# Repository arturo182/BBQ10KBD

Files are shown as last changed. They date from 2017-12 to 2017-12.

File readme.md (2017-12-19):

# Blackberry Q10 Keyboard

This document tries to summarize all the findings about the Blackberry Q10 keyboard, which seems interesting for DIY projects.
The keyboard has a nice feel to it, is just the right size for typing and is fairly cheap (around 3 USD on Aliexpress).  
It's available in black and white, there are versions with other letters like Arabic and Russian in addition to Latin. See [6] for details.  
It also has a 4 LED backlight and a built-in MEMS microphone which can come in handy.

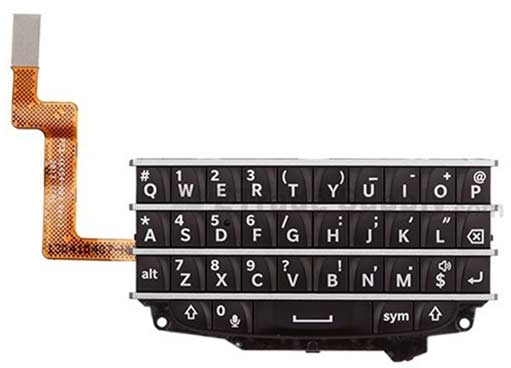
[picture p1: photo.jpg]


### Reversing on the pinout

Most of the work was done by others in [2] and [1], but after discovering the microphone, I was curious to see how it was connected and get the complete pinout of the keyboard. The flex PCB inside the keyboard is covered with a black film, but it is possible to remove the film by lifting a edge with a scalpel and slowly peeling it off, it might break mid-way but you can just lift the corner and continue.

A high resolution scan of the flex is available in this respository in `flex_scan.png`

Pinout:
```

    GND   1 | 28  GND
MIC_VDD   2 | 27  ROW7
    MIC   3 | 26  LEDA 1 & 2
   AGND   4 | 25  LEDK 1 & 4
    GND   5 | 24  LEDA 3 & 4
   ROW1   6 | 23  LEDK 2 & 3
   COL1   7 | 22  ROW6
   ROW2   8 | 21  ROW5
   COL2   9 | 20  ROW4
   COL3  10 | 19  COL5
    GND  11 | 18  ROW3
    GND  12 | 17  COL4
    GND  13 | 16  GND
    GND  14 | 15  GND
```

Since the numbering can be confusing (is it the plug or the receptacle?), see footprint below for clarification.

### KiCad resources

NOTE: These are not yet tested and while they are based on other people's working prototypes, I can't give a 100% guarantee these are correct, once I receive my board and verify everything, I will modify the document to reflect my findings.

Here is the final schematic symbol with the complete pinout, only one GND is visible, the rest is stacked under it and set to be invisible.

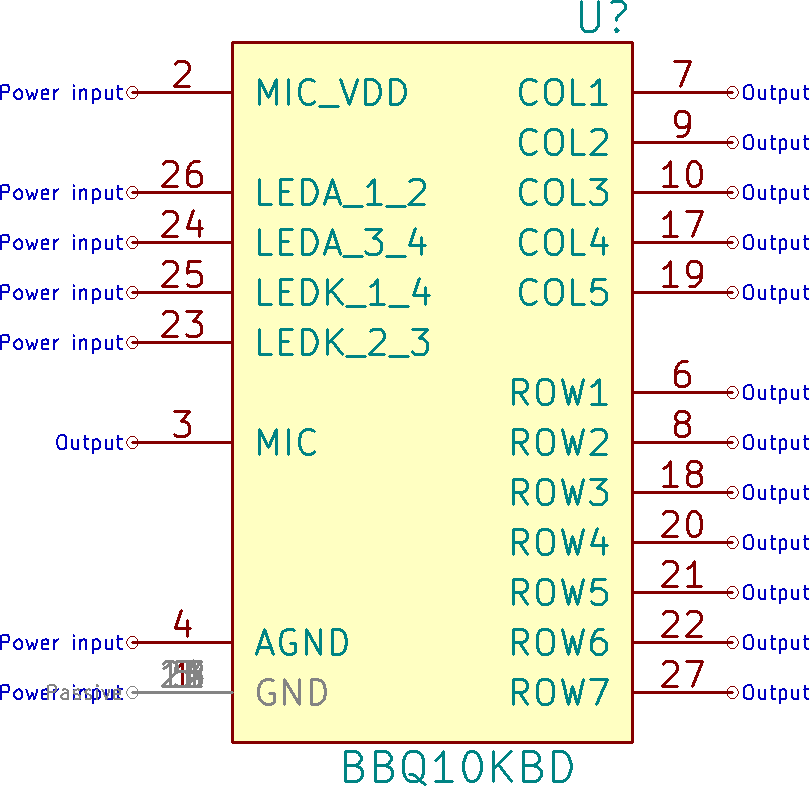
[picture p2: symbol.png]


The receptacle for the keyboard connector is the Hirose BM14B(0.8)-24DS-0.4V(53), the datasheet is freely available and Hirose even offers a 3d model of the connector, if you like it.

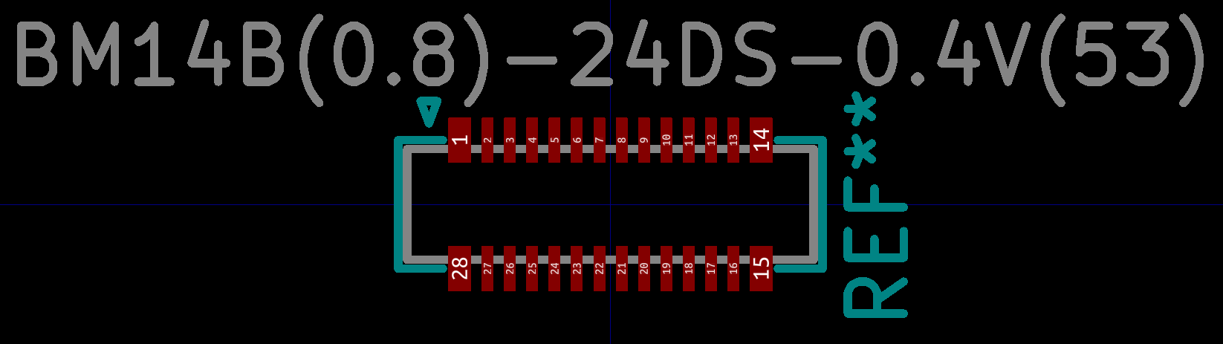
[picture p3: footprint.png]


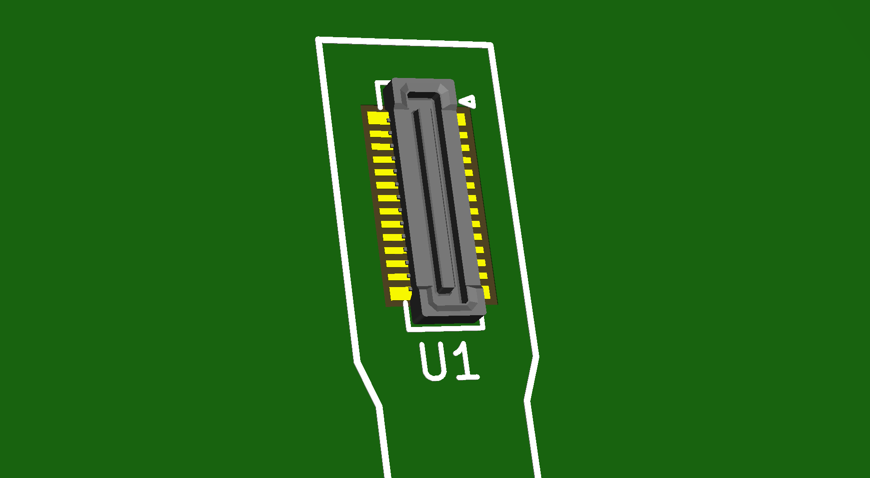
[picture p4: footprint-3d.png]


There's also a 3d model of the keyboard itself which I took from [4] and converted to wrl.

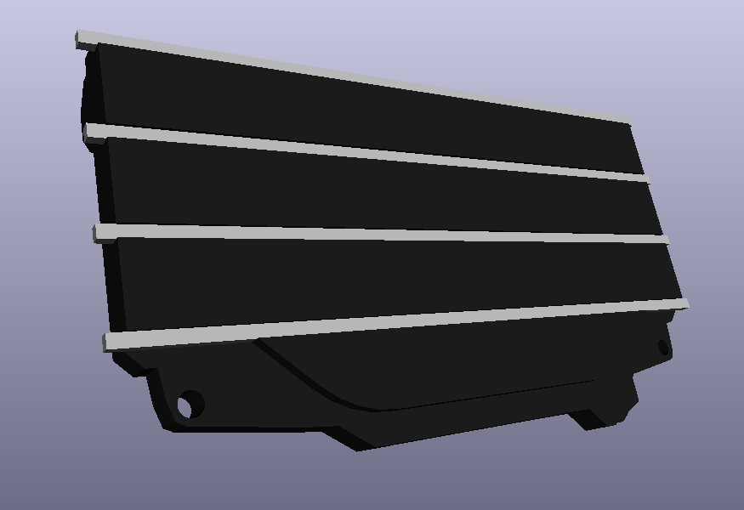
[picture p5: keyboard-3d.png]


I have a outline of the keyboard with the holes for tabs, but I haven't created a proper footprint file for it yet, will add in the near future:

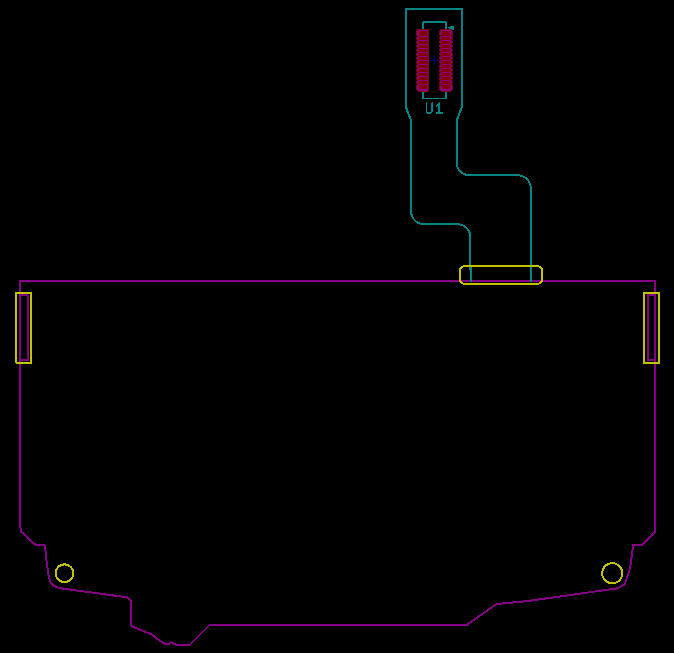
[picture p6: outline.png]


### Column/Row to key matrix

Copied from [3]

Regular keys:

| | COL1 | COL2 | COL3 | COL4 | COL5 | 
|---|---|---|---|---|---|
| **ROW1** | Q | E | R | U | O |
| **ROW2** | W | S | G | H | L |
| **ROW3** | sym  | D | T | Y | I |
| **ROW4** | A | P | R ⇧  | ↵ | ⌫ |
| **ROW5** | alt  | X | V | B | $ |
| **ROW6** | spac | Z | C | N | M |
| **ROW7** | 🎤 | L ⇧  | F | J | K |

Alternative keys:

| | COL1 | COL2 | COL3 | COL4 | COL5 |
|---|---|---|---|---|---|
| **ROW1** | #  | 2  | 3  | _  | +  |
| **ROW2** | 1  | 4  | /  | :  | "  |
| **ROW3** | | 5  | (  | )  | -  |
| **ROW4** | *  | @  | | | |
| **ROW5** | | 8  | ?  | !  |  🔊  |
| **ROW6** | | 7  | 9  | ,  | .  |
| **ROW7** | 0  | | 6  | ;  | '  |

### Blackberry UX

This part describes the way the Blackberry phone used the keyboard, might be a good reference and starting point for implementing a custom UX. Based on [7].

- Pressing the space twice adds a period and capitalizes the next letter
- Pressing and holding a letter key inserts capitalizes the letter
- Alt + R ⇧ turns on Caps Lock, pressing either shift turns it off
- Alt + L ⇧ turns on Num Lock, pressing either shift turns it off
- Pressing Alt will make the next key pressed insert a symbol from the alternative keys matrix
- Pressing Shift will make the next key pressed be capitalized

### Acknowledgements / Thanks

Huge thanks to JoeN for doing the initial reversing of the keyboard and finding the proper connector, and to WooDWorkeR for finding the backlight pinout and indirectly getting me interested in this keyboard in the first place.  
Also thanks to ccadic for providing the 3d model of the keyboard.

### Sources

[1] https://hackaday.io/project/27520-pimp-personal-information-manager-pager  
[2] https://www.eevblog.com/forum/beginners/how-to-connect-to-a-very-very-challanging-blackberry-q10-keyboard-connector/  
[3] https://forum.arduino.cc/index.php?topic=355709.0  
[4] https://grabcad.com/library/blackberry-q10-keyboard-shape-1  
[5] https://www.hirose.com/product/en/products/BM14/BM14B%280.8%29-24DS-0.4V%2853%29/  
[6] https://help.blackberry.com/en/blackberry-q10/10.3.1/help/mar1396885531697.html  
[7] https://help.blackberry.com/en/blackberry-q10/10.3.1/help/mba1343750483597.html

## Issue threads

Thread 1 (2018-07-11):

"Pressing and holding a letter key inserts capitalizes the letter" Do we know how long?

et-tommythorn, 2018-07-11:
Great work here.  We should capture as much detail as possible, including temporal behaviour such as how long to hold it before it transitions (I might be able to find the results from a BB Passport).

arturo182, 2018-07-11:
I can do some test with a real BBQ 10 and let you know.

tommythorn, 2018-07-11:
On the BB Passport (evaluated via iPhone 240 fps video), the transition from 'b' to 'B' starts after 163 ms.

tommythorn, 2018-07-11:
D'oh I counted frames, thus it should have been 163/240 = 679 ms

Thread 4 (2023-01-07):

Questions about backlight LED

drzacek, 2023-01-07:
Hello,

I've been wondering about the backlight LEDs. I dont quite understand the labels on those 4 pins, but I saw some i2c project and saw they just put 3.3V for the upper 2 pins and drive the bottom 2 to GND via mosfet.

Now the questions that I have:
1. Are there any resistors inside the keyboard module? So we can calculate the current and add another resistor for 5V
2. How much current do they drive? Is the transistor really necessary? If it's only few mA I would just sink it to GPIO.

arturo182, 2023-01-07:
The labels mean that pin 26 is the anode for LEDs 1 and 2, pin 24 is the anode for LEDs 3 and 4, 25 is the cathode for LEDs 1 and 4, and 23 for 2 and 3.

If you look at the scan of the flex PCB inside, you can see the resistors: https://github.com/arturo182/BBQ10KBD/blob/master/flex_scan.png

I don't have data on the current, but if you have a keyboard you can measure it quite easily.

The MOSFET is probably not needed but I wanted to stay on the safe side since I didn't know which MCU was going to be driving the backlight.
